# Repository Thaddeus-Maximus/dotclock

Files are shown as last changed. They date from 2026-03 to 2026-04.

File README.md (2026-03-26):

# dotclock

An ESP32-based alarm clock with a dot matrix LED display, rotary encoder interface, MP3 audio playback, and a web configuration UI.

## Features

- 32x8 dot matrix display (4x FC-16 / MAX7219 modules) with custom 3x6 pixel font
- Rotary encoder for all on-device interaction (press to cycle modes, turn to adjust)
- MP3 alarm tones stored on-chip (LittleFS, ~12MB available)
- Web UI for settings, time sync, WiFi config, and file management
- 25-step brightness (8 software PWM + 16 hardware levels)
- Persistent settings via NVS

## User Interface

The encoder button cycles through modes. The knob adjusts the value for the current mode. After 15 seconds of inactivity, the display returns to time mode.

| Mode | Icon | Knob Action | Notes |
|---|---|---|---|
| Time | (none, full-width HH:MM) | Dismisses alarm if ringing | Default mode |
| Volume | Speaker icon | 0-16 | Plays alarm tone as preview while adjusting |
| Brightness | Bulb icon | 1-24 | |
| Alarm | Bell icon | Adjusts alarm time by 1min (fast: 15min) | Scroll below 00:00 for OFF; defaults to OFF |
| Set Time | Clock icon | Adjusts system clock by 1min (fast: 15min) | |

When the alarm is ringing, the display flashes inverted at ~1.4Hz. Press button or turn knob to dismiss.

## Web Interface

WiFi AP: **dotclock** / password **dotclock1** / IP **192.168.4.1**

- Sync time from phone/browser (with timezone)
- Set alarm time, enable/disable, select alarm sound
- Adjust brightness and volume
- Connect to a WiFi network (AP+STA mode, enables SNTP)
- Upload, rename, and delete MP3 files

## Audio

- MP3 files, decoded via libhelix-mp3
- 8-bit DAC output on GPIO25 through a PAM8403 class-D amplifier
- GPIO25 driven low when idle to minimize speaker static

## Project Structure

- `HEDC-F001/` — Firmware (ESP-IDF v5.3.1 project)
- `HEDC-B002/` — Hardware (board schematic, see hardware reference below)

## TODO

- [x] Read encoder (debouncing, velocity detection)
- [x] Set display (writing, brightness control)
- [x] Custom 3x6 pixel font with 8x8 mode icons
- [x] MP3 audio playback
- [x] Alarm system with looping playback
- [x] Web interface (settings, file management, time sync)
- [x] Persistent settings (NVS)
- [x] WiFi AP + STA with SNTP
- [ ] Fine-tune font glyphs
- [ ] RC filter on DAC output for cleaner audio

# HEDC-B002 Hardware Reference

## Board Overview

The HEDC-B002 is an ESP32-based controller board with USB-C programming, SPI LED output (5V level-shifted), a rotary encoder with push button, an audio amplifier, and a 32.768kHz RTC crystal. The crystal, however, doesn't work right, it seems.

## Power

| Rail | Source | Regulator |
|---|---|---|
| +5V | USB-C (J1) | Direct from VBUS |
| +3.3V | +5V rail | U4 AMS1117-3.3 (SOT-223) |

## ESP32 GPIO Map

### Used GPIOs

| GPIO | Direction | Net Label | Function | Notes |
|---|---|---|---|---|
| IO0 | - | UART_~BOOT | Boot mode select | Auto-reset circuit via Q1. Do not use at runtime. |
| IO1 | TX | UART_TXD | Serial TX to CH340C | USB serial. Directly to J3 header pin alternate. |
| IO3 | RX | UART_RXD | Serial RX from CH340C | USB serial. |
| IO14 | Input | ES1 | Rotary encoder push switch | 5.1kΩ pull-up to 3.3V. Active LOW. |
| IO17 | Output | CS | SPI chip select | 3.3V → 5V via U1 74HCT244 → J3 pin 4 (CS_5V) |
| IO18 | Output | CLK | SPI clock | 3.3V → 5V via U1 74HCT244 → J3 pin 5 (CLK_5V) |
| IO23 | Output | DIN | SPI data out | 3.3V → 5V via U1 74HCT244 → J3 pin 3 (DIN_5V) |
| IO25 | Output | INL | Audio output to amplifier | AC-coupled into PAM8403 left channel input |
| IO26 | Input | EA1 | Rotary encoder channel A | 5.1kΩ pull-up to 3.3V |
| IO27 | Input | EB1 | Rotary encoder channel B | 5.1kΩ pull-up to 3.3V |
| IO32 | - | CRYSTAL_1 | 32.768kHz crystal (XIN) | Y1 CM315D32768DZFT, 22pF load caps (C7, C8) |
| IO33 | - | CRYSTAL_2 | 32.768kHz crystal (XOUT) | Y1 CM315D32768DZFT, 22pF load caps (C7, C8) |
| EN | - | UART_EN | Chip enable | Auto-reset circuit via Q1 + RC timing cap |

### Unused GPIOs

| GPIO | Pin # | Notes |
|---|---|---|
| IO2 | 24 | Explicitly no-connect on schematic |
| IO4 | 26 | Available |
| IO5 | 29 | Available (outputs PWM at boot) |
| IO12 | 14 | Available (boot fail if pulled high) |
| IO13 | 16 | Available |
| IO15 | 23 | Available (outputs PWM at boot) |
| IO16 | 27 | Available |
| IO19 | 31 | Available |
| IO21 | 33 | Available |
| IO22 | 36 | Available |
| IO34 | 6 | Available (input only, no pull-up/down) |
| IO35 | 7 | Available (input only, no pull-up/down) |
| SENSOR_VP (IO36) | 4 | Available (input only) |
| SENSOR_VN (IO39) | 5 | Available (input only) |

## Components

### U3 — CH340C (USB-to-Serial)

SOIC-16 USB-UART bridge. Internal oscillator (no external crystal). Connected to USB-C connector J1.

| CH340C Pin | Net | Connects To |
|---|-----|---|
| TXD | UART_TXD | ESP32 IO1 (RXD0) |
| RXD | UART_RXD | ESP32 IO3 (TXD0) |
| ~DTR | DTR | Q1 auto-reset circuit |
| ~RTS | RTS | Q1 auto-reset circuit |
| UD+/UD- | USB D+/D- | J1 USB-C connector |
| V3 | - | 100nF decoupling cap (C6) to GND |

### Q1 — MMDT3904-7-F (Auto-Reset)

Dual NPN transistor (SOT-363) implementing the standard ESP32 auto-programming circuit. Cross-coupled: RTS drives IO0 (BOOT), DTR drives EN, so a DTR/RTS sequence enters the bootloader automatically.

### U1 — 74HCT244 (Level Shifter)

TSSOP-20 octal buffer. Powered from +5V. Converts 3.3V ESP32 SPI signals to 5V for J3 output. Bank 1 active (OE tied to GND), bank 2 active but unused.

| Input (3.3V) | Output (5V) | Signal |
|---|---|---|
| 1A0 ← CS (IO17) | 1Y0 → CS_5V | Chip select |
| 1A1 ← CLK (IO18) | 1Y1 → CLK_5V | Clock |
| 1A2 ← DIN (IO23) | 1Y2 → DIN_5V | Data |

### J3 — 5-Pin LED Output Connector (FC-16 footprint)

| Pin | Signal |
|-----|---|
| 1 | +5V |
| 2 | GND |
| 3 | DIN_5V |
| 4 | CS_5V |
| 5 | CLK_5V |

This is the SPI output for driving an LED matrix or display panel.

### SW1 — PEC09-2320F-S0015 (Rotary Encoder)

Bourns horizontal-mount rotary encoder with push button. All signals pulled up to 3.3V with 5.1kΩ resistors.

| Function | Net | GPIO | Active State |
|---|-----|---|---|
| Encoder A | EA1 | IO26 | LOW pulses |
| Encoder B | EB1 | IO27 | LOW pulses |
| Push switch | ES1 | IO14 | LOW when pressed |

### U2 — PAM8403DR (Audio Amplifier)

SOP-16 class-D stereo amplifier, powered from +5V. Left channel input (INL) driven from ESP32 IO25 through a coupling capacitor. Speaker output on SPK1 header (marked DNP — do not populate).

| Connection | Detail |
|---|---|
| Input | IO25 → coupling cap → INL (pin 7) |
| Output | LOUT+/LOUT- → SPK1 (2-pin header) |
| Power | +5V / GND |

### Y1 — CM315D32768DZFT (RTC Crystal)

32.768kHz crystal connected to IO32/IO33 with 22pF load capacitors (C7, C8). Provides a precise timebase for RTC functionality.

### J1 — USB-C Connector (UJ20-C-V-C-1-SMT-TR)

USB 2.0 Type-C receptacle (14-pin). CC1/CC2 have 5.1kΩ pull-downs (R6, R7) for device identification.

## Code Quick-Reference

```cpp
// --- Pin Definitions ---

// SPI LED output (directly usable with hardware SPI: VSPI)
#define PIN_LED_CS    17  // SPI chip select
#define PIN_LED_CLK   18  // SPI clock (VSPI CLK)
#define PIN_LED_DIN   23  // SPI MOSI (VSPI MOSI)

// Rotary encoder (active LOW, external 5.1k pull-ups)
#define PIN_ENC_A     26  // Encoder channel A
#define PIN_ENC_B     27  // Encoder channel B
#define PIN_ENC_SW    14  // Encoder push switch

// Audio output (PWM/DAC → PAM8403 amplifier)
#define PIN_AUDIO     25  // DAC1 output (IO25 is DAC channel 1)

// UART (directly to CH340C — used by USB serial, avoid reassigning)
// #define PIN_TXD0    1
// #define PIN_RXD0    3

// RTC crystal (do not use as GPIO)
// IO32 — XTAL 32.768kHz XIN
// IO33 — XTAL 32.768kHz XOUT
```

### Notes for Firmware

- **SPI**: IO17/IO18/IO23 map to the default VSPI bus (CLK=18, MOSI=23). IO17 is used as CS but is not the default VSPI CS0 (IO5), so configure it manually.
- **Audio**: IO25 is one of the ESP32's two DAC outputs (DAC1). You can use `dacWrite(25, value)` for simple waveforms, or configure I2S for higher quality audio output to the PAM8403.
- **Rotary encoder**: Use interrupt-driven decoding on IO26/IO27. The push button on IO14 should be debounced in software.
- **RTC crystal**: IO32/IO33 are dedicated to the 32.768kHz crystal. Use the ESP32's internal RTC with this external crystal for accurate timekeeping. Configure via `rtc_clk_32k_enable()` or the ESP-IDF RTC API.
- **Boot strapping**: IO0 is used for boot mode (auto-reset handles this). IO2 is NC. IO12/IO15 affect boot — if using them, ensure they're not pulled to unexpected states at power-on.

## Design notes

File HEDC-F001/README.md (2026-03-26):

# HEDC-F001 Firmware

ESP-IDF v5.3.1 firmware for the dotclock alarm clock.

## Building

```
idf.py set-target esp32
idf.py build
idf.py flash monitor
```

Flash size must be set to **16MB** in menuconfig (`Serial flasher config > Flash size`).

## Partition Layout

Defined in `partitions.csv`:

| Partition | Type | Size | Purpose |
|---|---|---|---|
| nvs | data | 24KB | Settings (brightness, volume, alarm, WiFi) |
| otadata | data | 8KB | OTA state |
| ota_0 | app | 2MB | Application slot 0 |
| ota_1 | app | 2MB | Application slot 1 |
| storage | data | ~12MB | LittleFS filesystem for MP3 files |

## Source Files

| File | Description |
|---|---|
| `main.c` | App entry point, encoder UI state machine (5 modes), idle timeout |
| `display.c` | MAX7219 driver, framebuffer, 3x6 font, 8x8 mode icons, software PWM brightness |
| `display.h` | Display API, pin definitions, brightness constants, icon enum |
| `encoder.c` | Quadrature decoder via GPIO ISR, velocity detection, button debounce |
| `encoder.h` | Encoder pin definitions, state struct |
| `audio.c` | MP3 decode (libhelix-mp3) to 8-bit DAC via `dac_continuous` driver |
| `audio.h` | Audio API, volume constants |
| `settings.c` | NVS-backed persistent settings (load/save/getters/setters) |
| `settings.h` | Settings API |
| `alarm.c` | Alarm check timer (1s), looping playback, time management (epoch, timezone) |
| `alarm.h` | Alarm API, time helpers (`time_is_set`, `time_set_epoch`, `time_set_tz`) |
| `webserver.c` | HTTP server, 11 URI handlers, WiFi AP+STA, SNTP |
| `webserver.h` | Webserver API |
| `webpage.html` | Web UI source (compiled to `webpage.h` by `webpage_compile.py`) |
| `simple_dns_server.c` | Captive portal DNS responder |

## Dependencies

Defined in `idf_component.yml`:

- `chmorgan/esp-libhelix-mp3` ^1.0.3 -- MP3 decoding
- `joltwallet/littlefs` ^1.20.3 -- LittleFS filesystem

## Display

### Hardware

4x FC-16 modules (MAX7219), daisy-chained via SPI3 at 1MHz.

| Signal | GPIO |
|---|---|
| CS | 17 |
| CLK | 18 |
| DIN | 23 |

### Fonts

Two fonts are defined (3x5 is commented out, 3x6 is active):

**3x6 font** (`font_3x6`): 3 columns, 6 rows per glyph, LSB = top row. Indices:
- 0-9: digits (user-customized shapes)
- 10: minus/dash
- 11: space
- 12-37: A-Z

### Rendering Functions

| Function | Description |
|---|---|
| `display_time(h, m, colon)` | Full-width HH:MM with double-thick colon, y-offset 1 |
| `display_dashes()` | Full-width --:-- (same layout as time, for "not set" state) |
| `display_text(str)` | Left-aligned text |
| `display_number(num)` | Right-aligned number |
| `display_icon_time(icon, h, m)` | 8x8 icon on panel 0 + HHMM on panels 1-3 |
| `display_icon_number(icon, num)` | 8x8 icon on panel 0 + number centered on panels 1-3 |
| `display_icon_text(icon, str)` | 8x8 icon on panel 0 + text centered on panels 1-3 |
| `display_invert()` | XOR entire framebuffer (used for alarm flash) |

### Brightness

25 levels (0-24). `DISPLAY_BRIGHTNESS_MAX` = 24.

- Level 0: display off
- Levels 1-8: software PWM at hardware intensity 0 (~500Hz, 8 duty phases)
- Levels 9-24: hardware intensity registers 0-15

PWM race condition is handled by setting `pwm_duty = 0` before `esp_timer_stop()`.

### Mode Icons

8x8 pixel icons stored as column bytes (MSB = top), one per UI mode:

| Icon | Enum | Usage |
|---|---|---|
| Bell | `DISPLAY_ICON_ALARM` | Alarm time setting |
| Clock | `DISPLAY_ICON_SET_TIME` | System time setting |
| Speaker | `DISPLAY_ICON_VOLUME` | Volume adjustment |
| Bulb | `DISPLAY_ICON_BRIGHTNESS` | Brightness adjustment |

## Encoder

PEC09 rotary encoder with quadrature decoding in ISR. `DRAM_ATTR` is required on the lookup table (ISR runs with flash cache disabled during NVS/LittleFS writes).

- 2 raw edges per detent, divided by 2 in `encoder_read()`
- Velocity detection via ring buffer of edge timestamps
- Fast threshold: 100 detents/sec
- Button debounce: 20ms in ISR

## Audio

- MP3 decode via libhelix-mp3 in a dedicated FreeRTOS task (priority 10)
- Output: `dac_continuous` driver on GPIO25 (DAC1), 8-bit mono
- DMA: 8 descriptors x 2048 bytes, input buffer 4096 bytes
- GPIO25 driven low when not playing to reduce idle speaker static
- Volume: 16 levels, applied as bit-shift attenuation on PCM samples

## Alarm

- 1-second `esp_timer` callback checks if current time matches alarm time
- When triggered, plays the selected MP3 file in a loop (re-triggers on playback end)
- Dismissed by encoder button press or knob turn
- Display flashes inverted at ~1.4Hz (350ms per phase) while ringing
- Alarm defaults to OFF; enabled by scrolling up from OFF in the alarm menu
- Scrolling below 00:00 sets alarm to OFF; scrolling above 23:59 wraps to 00:00

## Settings (NVS)

NVS namespace: `dotclock`

| Key | Type | Default | Description |
|-----|---|---|---|
| brightness | u8 | 1 | Display brightness (1-24) |
| volume | u8 | 8 | Audio volume (0-16) |
| alm_hour | u8 | 0 | Alarm hour |
| alm_min | u8 | 0 | Alarm minute |
| alm_en | u8 | 0 | Alarm enabled |
| alm_file | string | "" | Alarm sound filename |
| wifi_ssid | string | "" | STA WiFi SSID |
| wifi_pass | string | "" | STA WiFi password |

## Web Server

WiFi SoftAP is always active: SSID `dotclock`, password `dotclock1`, IP `192.168.4.1`. Optional STA mode connects to a saved WiFi network (AP+STA concurrent).

### Endpoints

| Method | Path | Description |
|---|---|---|
| GET | `/` | Serve web UI (compiled from `webpage.html`) |
| GET | `/settings` | JSON: all settings + current time + WiFi status |
| POST | `/settings` | Update settings (form-encoded) |
| POST | `/time` | Set epoch + timezone offset (from browser) |
| POST | `/wifi` | Save WiFi credentials and connect |
| GET | `/files` | JSON array of files on storage |
| POST | `/upload` | Upload file (multipart/form-data) |
| POST | `/delete` | Delete file (`?file=name`) |
| POST | `/rename` | Rename file (`?from=old&to=new`) |
| POST | `/alarm/test` | Play alarm sound immediately |
| POST | `/alarm/stop` | Stop alarm playback |

### Time Sync

The browser sends `Math.floor(Date.now()/1000)` as epoch and `new Date().getTimezoneOffset()` as tz offset. The ESP32 sets the system clock and configures a POSIX TZ environment variable. When STA WiFi is connected, SNTP is also enabled.

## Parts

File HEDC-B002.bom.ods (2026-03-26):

Reference | Value | Datasheet | Footprint | Qty | DNP | DIGIKEY PN
C1,C2,C5 | 100nF | ~ | Capacitor_SMD:C_0603_1608Metric | 3 |  | 1276-1012-1-ND
C3,C4,C6 | 1uF | ~ | Capacitor_SMD:C_0603_1608Metric | 3 |  | 1276-1946-1-ND
C7,C11 | 470nF | ~ | Capacitor_SMD:C_0603_1608Metric | 2 |  | 1276-1062-1-ND
C8,C9 | 22pF | ~ | Capacitor_SMD:C_0603_1608Metric | 2 |  | 1276-1023-1-ND
J2 | Conn_01x02 | ~ | Connector_PinHeader_2.54mm:PinHeader_1x02_P2.54mm_Vertical | 1
J4 | Conn_01x05 | ~ | footprints:FC-16 | 1
J5 | USB_C_Receptacle_USB2.0_14P | https://www.usb.org/sites/default/files/documents/usb_type-c.zip | Connector_USB:USB_C_Receptacle_GCT_USB4115-03-C | 1 |  | 2223-UJ20-C-V-C-1-SMT-TRCT-ND
Q3 | MMDT3904 | http://www.diodes.com/_files/datasheets/ds30088.pdf | Package_TO_SOT_SMD:SOT-363_SC-70-6 | 1 |  | MMDT3904-FDICT-ND
R1,R2,R3,R4,R5,R6,R7,R8,R9 | 5.1k | ~ | Resistor_SMD:R_0805_2012Metric | 9 |  | CR0805-FX-5101ELFCT-ND
SW1 | PEC11H-4120F-S0020 | PEC11H-4120F-S0020 | Rotary_Encoder:RotaryEncoder_Bourns_Horizontal_PEC09-2xxxF-Sxxxx | 1 |  | PEC09-2320F-S0015-ND
U1 | CH340C | https://datasheet.lcsc.com/szlcsc/Jiangsu-Qin-Heng-CH340C_C84681.pdf | Package_SO:SOIC-16_3.9x9.9mm_P1.27mm | 1
U2 | 74HCT04 | https://assets.nexperia.com/documents/data-sheet/74HC_HCT04.pdf | Package_SO:TSSOP-14_4.4x5mm_P0.65mm | 1 |  | 31-74HCT04T14-13CT-ND
U3 | PAM8403D | https://www.diodes.com/assets/Datasheets/products_inactive_data/PAM8403.pdf | Package_SO:SOP-16_3.9x9.9mm_P1.27mm | 1 |  | PAM8403DRDICT-ND
U5 | ESP32-WROOM-32 | https://www.espressif.com/sites/default/files/documentation/esp32-wroom-32_datasheet_en.pdf | RF_Module:ESP32-WROOM-32 | 1
U8 | AMS1117-3.3 | http://www.advanced-monolithic.com/pdf/ds1117.pdf | Package_TO_SOT_SMD:SOT-223-3_TabPin2 | 1 |  | 4518-AMS1117-3.3CT-ND
Y1 | CM315D32768DZFT |  | footprints:XTAL_CM315D32768DZFT | 1 |  | 300-8814-1-ND

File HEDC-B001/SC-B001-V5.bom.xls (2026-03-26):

Id | Designator | Footprint | Quantity | Designation | PN | Supplier | DigiKey PN
14 | C1 | CP_Elec_10x12.5 | 1 | 680uF | A783MW687M1VLAS011 | DigiKey | 399-A783MW687M1VLAS011CT-ND
33 | C11,C10 | C_0603_1608Metric | 2 | 22pF | CL10C220JB8NNNC | DigiKey | 1276-1023-1-ND
15 | C2,C12,C3 | C_0805_2012Metric | 3 | 4.7uF | CL21A475KLCLQNC | DigiKey | 1276-6722-1-ND
10 | C4 | C_0603_1608Metric | 1 | 1nF | CL10B102KB8NNNC | DigiKey | 1276-1018-1-ND
19 | C5 | CP_Elec_8x10 | 1 | 220uF | A787KN227M1VLAS027 | DigiKey | 399-A787KN227M1VLAS027CT-ND
7 | C6,C14,C9 | C_0603_1608Metric | 3 | 100nF | CL10F104ZB8NNNC | DigiKey | 1276-1012-2-ND
5 | D3,D4,D5,D1,D2 | D_SMA | 5 | B340A-13-F | B340A-13-F | DigiKey | B340A-FDICT-ND
22 | J_RF1 | RX470C-V01 | 1 | RX470-4 | RX470C-V01 | QiaChip
2 | J1,J2,J3,J4 | JST_EH_B3B-EH-A_1x03_P2.50mm_Vertical | 4 | B3B-EH-A | B3B-EH-A | DigiKey | 455-B3B-EH-A-ND
23 | J7 | PinHeader_1x07_P2.54mm_Vertical | 1 | Conn_01x07 | PH1-07-UA | DigiKey | 2057-PH1-07-UA-ND
 | J8 | MSD-1-A | 1 | MSA-1-A | MSA-1-A | DigiKey | 2223-MSD-1-ATR-ND
3 | JA3,JA1,JB2,J_PV-1,J_BAT+1,J_BAT-1,JB1,JA2,J_PV+1,J_GND1,J_BAT+2 | TE_1217861-1 | 11 | Conn_01x01_Pin | 1217861-1 | DigiKey | A100452TR-ND
16 | KA3,KA2,KB2 | RELAY_A161CS12VDC.64 | 3 | A161CS12VDC.64 | A161CS12VDC.64 | DigiKey | 2449-A161CS12VDC.64-ND
4 | KB1,KA1 | A31CSP12VDC2 | 2 | A31CSP12VDC2 | A31CSP12VDC2 | DigiKey | 2449-A31CSP12VDC2-ND
28 | L1 | IND_IFDC5050HZER_VIS | 1 | IFDC5050HZER330M | IFDC5050HZER330M | DigiKey | 541-IFDC5050HZER330MCT-ND
36 | L2 | RES_CIGT201610_SAM | 1 | CIGT201610LH2R2MNE | CIGT201610LH2R2MNE | DigiKey | 1276-6911-1-ND
29 | LED1 | WP934SA&slash_3GD_KNB | 1 | WP934SA/3GD | WP934SA/3GD | DigiKey | 754-1289-ND
12 | Q1,Q2 | SOT-23 | 2 | 2N7002 | 2N7002 | DigiKey | 2N7002NCT-ND
21 | R1 | R_0805_2012Metric | 1 | 22k | CRCW080522K0FKEAC | DigiKey | 541-4150-1-ND
27 | R11,R12,R13,R14 | R_0805_2012Metric | 4 | 1k | CRCW08051K00FKEAC | DigiKey | 541-3977-1-ND
6 | R17,R16,R15 | R_0805_2012Metric | 3 | 100 | CRCW0805100RFKEAC | DigiKey | 541-3979-1-ND
9 | R19,R9,R8,R18,R7,R20,R23 | R_0805_2012Metric | 7 | 4.7k | CRCW08054K70FKEAC | DigiKey | 541-4131-1-ND
30 | R2 | R_0805_2012Metric | 1 | 2.2k | CRCW08052K20FKEA | DigiKey | 541-2.20KCCT-ND
24 | R3 | R_0805_2012Metric | 1 | 33k | CRCW080533K0FKEA | DigiKey | 541-33.0KCCT-ND
26 | R4 | R_0805_2012Metric | 1 | 1M | CRCW08051M00FKEAC | DigiKey | 541-4135-1-ND
20 | R5 | R_0805_2012Metric | 1 | 150k | CRCW0805150KFKEAC | DigiKey | 541-CRCW0805150KFKEACCT-ND
31 | R6 | R_0805_2012Metric | 1 | 42.2k | CRCW080542K2FKEA | DigiKey | 541-42.2KCCT-ND
8 | SW1 | SW_Tactile_SPST_Angled_PTS645Vx31-2LFS | 1 | TS11-674-80-BK-260-RA-D | TS11-674-80-BK-260-RA-D | DigiKey | 2223-TS11-674-80-BK-260-RA-D-ND
13 | U1 | VREG_LM2596S-ADJ | 1 | LM2596S-ADJ | LM2596S-ADJ | DigiKey | LM2596DSADJGOS-ND
1 | U11 | TSSOP-24_4.4x7.8mm_P0.65mm | 1 | TCA9535PWR | NCA9535PWJ | DigiKey | 1727-NCA9535PWJTR-ND
17 | U2 | SOTFL50P160X60-8N | 1 | TPS629210DRLR | TPS629210DRLR | DigiKey | 296-TPS629210DRLRCT-ND
34 | U3 | ESP32-WROOM-32 | 1 | ESP32-WROOM-32 | ESP32-WROOM-32E-N8 | DigiKey | 5407-ESP32-WROOM-32E-N8TR-ND
35 | U4 | SOIC127P600X175-16N | 1 | ULN2003ADR | ULN2003ADR | DigiKey | 296-1368-1-ND
25 | U5,U6 | SMDIP-8_W9.53mm | 2 | LTV-827S | LTV-827S | DigiKey | 160-1369-5-ND
11 | U9 | ACS37220LEZATR200B5 | 1 | ACS37220LEZATR-100B3 | ACS37220LEZATR-100B3 | DigiKey | 620-ACS37220LEZATR-100B3CT-ND
32 | Y1 | XTAL_CM315D32768DZFT | 1 | CM315D32768DZFT | CM315D32768DZFT | DigiKey | 300-8814-1-ND

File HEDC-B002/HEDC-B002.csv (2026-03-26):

Id | Designator | Footprint | Quantity | Designation | Supplier and ref
1 | R2,R11,R8,R4,R6,R1,R3,R9,R7,R10 | R_0805_2012Metric | 10 | 5.1k | CR0805-FX-5101ELFCT-ND
2 | SW1 | RotaryEncoder_Bourns_Horizontal_PEC09-2xxxF-Sxxxx | 1 | PEC09-2320F-S0015 | PEC09-2320F-S0015-ND
3 | C4,C5,C10 | C_0603_1608Metric | 3 | 1uF | 1276-1946-1-ND
4 | C9,C1,C6 | C_0603_1608Metric | 3 | 100nF | 1276-1012-1-ND
5 | C2,C3 | C_0603_1608Metric | 2 | 470nF | 1276-1062-1-ND
6 | J1 | USB_C_Receptacle_GCT_USB4115-03-C | 1 | UJ20-C-V-C-1-SMT-TR | 2223-UJ20-C-V-C-1-SMT-TRCT-ND
7 | C7,C8 | C_0603_1608Metric | 2 | 22pF | 1276-1023-1-ND
8 | U1 | TSSOP-20_4.4x6.5mm_P0.65mm | 1 | 74HCT244 | MC74HCT244ADTGOSCT-ND
9 | SPK1 | PinHeader_1x02_P2.54mm_Vertical | 1 | Conn_01x02
10 | Q1 | SOT-363_SC-70-6 | 1 | MMDT3904-7-F | MMDT3904-FDICT-ND
11 | U2 | SOP-16_3.9x9.9mm_P1.27mm | 1 | PAM8403DR | PAM8403DRDICT-ND
12 | U3 | SOIC-16_3.9x9.9mm_P1.27mm | 1 | CH340C
13 | U4 | SOT-223-3_TabPin2 | 1 | AMS1117-3.3 | 4518-AMS1117-3.3CT-ND
14 | R5 | R_0805_2012Metric | 1 | 2.7k | CR0805-FX-2701ELFCT-ND
15 | U5 | ESP32-WROOM-32 | 1 | ESP32-WROOM-32
16 | Y1 | XTAL_CM315D32768DZFT | 1 | CM315D32768DZFT | 300-8814-1-ND
17 | J3 | FC-16 | 1 | Conn_01x05
Id | Designator | Footprint | Quantity | Designation | Supplier and ref
1 | TH3,TH1,TH2 | R_0805_2012Metric | 3 | SMD0805B100TFT | SMD0805B050TF
2 | U11,U12 | SOIC127P600X175-16N | 2 | ULN2003ADR | 296-1368-1-ND
3 | D1 | D_SMA | 1 | B340A-13-F | B340A-FDICT-ND
4 | C2,C17,C11,C1,C9,C15,C12,C10,C16,C14 | C_0603_1608Metric | 10 | 100nF | 1276-1012-1-ND
5 | C4,C7,C13,C6,C8 | C_0805_2012Metric | 5 | 4.7uF
6 | K7,K11,K5,K1,K3,K2,K4,K8,K6,K12,K9,K10 | RELAY_A161CS12VDC.64 | 12 | A161CS12VDC.64 | 2449-A161CS12VDC.64-ND
7 | U9 | TSSOP-20_4.4x6.5mm_P0.65mm | 1 | 74HCT244 | MC74HCT244ADTGOSCT-ND
8 | U6,U8,U7 | TSSOP-14_4.4x5mm_P0.65mm | 3 | MCP3204 | MCP3204T-CI/STCT-ND
9 | ,,,, |  | 5
10 | D2,D3,D4 | LED_D5.0mm | 3 | LED | 2007-BL-BBX1V4V-2-B02-ND
11 | R17,R14,R18 | R_0805_2012Metric | 3 | 100 | CR0805-FX-1000ELFCT-ND
12 | J1,J2 | AT04-4P-BMxx | 2 | Conn_01x04 | 889-1893-ND
13 | J_BAT-1,J_BAT+1 | S93520 | 2 | S93520 | 2101-S93520-ND
14 | R11 | R_0805_2012Metric | 1 | 80.6k | CR0805-FX-8062ELFCT-ND
15 | R6,R3,R13,R5,R4,R1,R2 | R_0805_2012Metric | 7 | 10k | CR0805-FX-1002ELFCT-ND
16 | U5,U3 | SOTFL50P160X60-8N | 2 | TPS629210DRLR
17 | R15,R12,R16 | R_0805_2012Metric | 3 | 5.1k | CR0805-FX-5101ELFCT-ND
18 | C5 | CP_Elec_10x12.5 | 1 | 680uF
19 | J3 | AT04-6P-BMXX | 1 | Conn_01x06
20 | U14,U15,U13 | XDCR_ACS71240KEXBLT-050U5 | 3 | ACS71240KEXBLT-050U5 | 620-2050-1-ND
21 | L1,L2 | RES_CIGT201610_SAM | 2 | CIGT201610LH2R2MNE | 1276-6911-1-ND
22 | U4 | ESP32-WROOM-32 | 1 | ESP32-WROOM-32
23 | J6,J4,J5 | AT04-12PX-BMXX | 3 | Conn_01x12 | 889-1923-ND
24 | R8 | R_0805_2012Metric | 1 | 150k | CR0805-FX-1503ELFCT-ND
25 | R7 | R_0805_2012Metric | 1 | 1M | CR0805-FX-1004ELFCT-ND
26 | U1 | DBZ0003A-MFG | 1 | DRV5033AJQDBZR | 296-38454-1-ND
27 | U10 | TSSOP-24_4.4x7.8mm_P0.65mm | 1 | TCA9535PWR | 296-25129-1-ND
28 | R9,R10 | R_0805_2012Metric | 2 | 42.2k | CR0805-FX-4222ELFCT-ND
Id | Designator | Footprint | Quantity | Designation | Supplier and ref
1 | TH2,TH1 | R_0805_2012Metric | 2 | SMD0805B100TFT
2 | R6,R2,R4,R3,R13,R7,R5,R1,R8 | R_0805_2012Metric | 9 | 4.7k
3 | C5,C7 | C_0603_1608Metric | 2 | 100nF
4 | R9 | R_0805_2012Metric | 1 | 120
5 | C3,C4,C2 | C_0805_2012Metric | 3 | 4.7uF
6 | R10 | R_0805_2012Metric | 1 | 1M
7 | J4,J5,J6 | PhoenixContact_SPT_1.5_2-H-3.5_1x02_P3.5mm_Horizontal | 3 | Conn_01x02
8 | Q1 | SOT-23 | 1 | 2N7002 | 4878-2N7002CT-ND
9 | U2 | SOTFL50P160X60-8N | 1 | TPS629210DRLR
10 | J1 | PinSocket_1x07_P2.54mm_Vertical | 1 | Conn_01x07
11 | U1 | ESP32-WROOM-32 | 1 | ESP32-WROOM-32
12 | J2 | TE_2-1734839-5_1x25-1MP_P0.5mm_Horizontal | 1 | Conn_01x25
13 | D4 | D_SMA | 1 | B340A-13-F
14 | L2 | RES_CIGT201610_SAM | 1 | CIGT201610LH2R2MNE
15 | R12 | R_0805_2012Metric | 1 | 42.2k | CR0805-FX-4222ELFCT-ND
16 | R11 | R_0805_2012Metric | 1 | 150k | CR0805-FX-1503ELFCT-ND
17 | C1 | CP_Elec_10x12.5 | 1 | 680uF
18 | SW8,SW6,SW5,SW4,SW7,SW3 | SW_PUSH_6mm_H9.5mm | 6 | SW_Push | 2223-TS02-66-100-BK-260-SCR-D-ND
19 | SW2,SW1 | PEC11H-4x20F-Sxxxx_BRN | 2 | PEC11H-4120F-S0020 | 118-PEC11H-4120F-S0020-ND
20 | J3 | G240160A-FTW-DW63 | 1 | Conn_01x02 | 2632-G240160A-FTW-DW63-ND

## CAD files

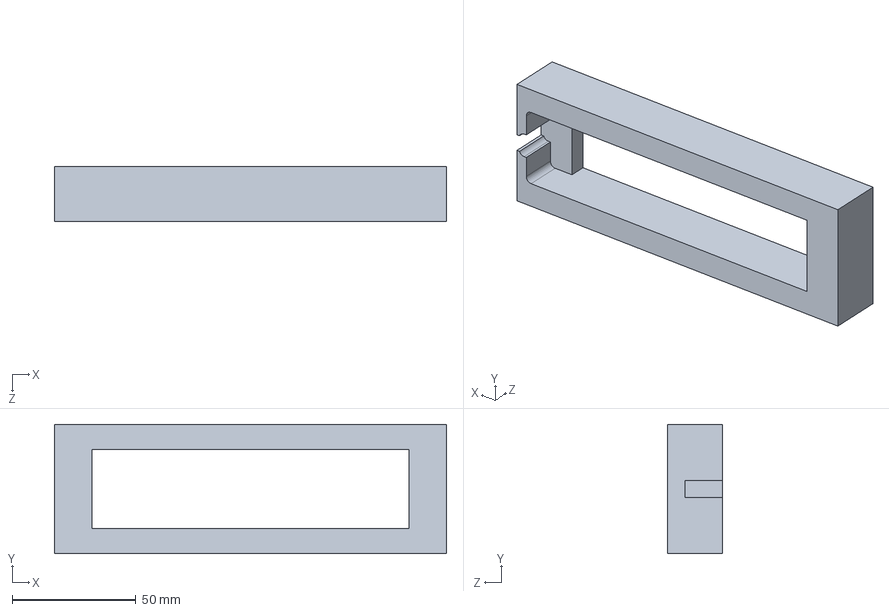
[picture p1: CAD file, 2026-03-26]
HEDC-0001.SLDPRT
158.5 x 52.3 x 22.2 mm

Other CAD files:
HEDC-0001.SLDDRW

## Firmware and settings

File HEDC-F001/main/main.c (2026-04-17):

#include <stdio.h>
#include <time.h>
#include <sys/time.h>
#include "freertos/FreeRTOS.h"
#include "freertos/task.h"
#include "esp_littlefs.h"
#include "esp_log.h"
#include "encoder.h"
#include "display.h"
#include "audio.h"
#include "settings.h"
#include "alarm.h"
#include "webserver.h"

static const char *TAG = "main";

extern bool time_is_set(void);
extern void time_set_epoch(int64_t epoch);

typedef enum {
	MODE_TIME,
	MODE_ALARM,
	MODE_VOLUME,
	MODE_BRIGHTNESS,
	MODE_SET_TIME,
	MODE_NETWORK,
	MODE_COUNT
} ui_mode_t;

#define IDLE_TIMEOUT  1500  // 15 seconds at 10ms ticks

// Default epoch for initial time set (2025-01-01 12:00:00 UTC)
#define DEFAULT_EPOCH 1735732800LL

static void init_storage(void)
{
	esp_vfs_littlefs_conf_t cfg = {
		.base_path = "/storage",
		.partition_label = "storage",
		.format_if_mount_failed = true,
		.dont_mount = false,
	};
	esp_err_t ret = esp_vfs_littlefs_register(&cfg);
	if (ret != ESP_OK) {
		ESP_LOGE(TAG, "LittleFS mount failed: %s", esp_err_to_name(ret));
		return;
	}

	size_t total = 0, used = 0;
	esp_littlefs_info("storage", &total, &used);
	ESP_LOGI(TAG, "Storage: %d KB total, %d KB used", total / 1024, used / 1024);
}

// Adjust alarm time by delta minutes
// Below 00:00 → OFF; above 23:59 → wraps to 00:00
// From OFF, scrolling up → 00:00 (enabled)
static void adjust_alarm_time(int delta)
{
	if (!settings_get_alarm_enabled()) {
		if (delta > 0) {
			settings_set_alarm_enabled(true);
			settings_set_alarm_time(0, 0);
			alarm_reschedule();
		}
		return;
	}

	int total = settings_get_alarm_hour() * 60 + settings_get_alarm_minute() + delta;

	if (total < 0) {
		// Scrolled below 00:00 → OFF
		settings_set_alarm_enabled(false);
		alarm_reschedule();
		return;
	}

	// Wrap at top (23:59 + 1 → 00:00, stays enabled)
	total = total % (24 * 60);

	settings_set_alarm_time(total / 60, total % 60);
	alarm_reschedule();
}

// Adjust the system clock by delta minutes
static void adjust_system_time(int delta)
{
	// Seed with a reasonable epoch if time was never set
	if (!time_is_set()) {
		time_set_epoch(DEFAULT_EPOCH);
	}

	struct timeval tv;
	gettimeofday(&tv, NULL);
	tv.tv_sec += delta * 60;
	if (tv.tv_sec < 0) tv.tv_sec = 0;
	settimeofday(&tv, NULL);
}

// Start/stop volume preview tone on mode transitions
static void on_mode_change(ui_mode_t prev, ui_mode_t next)
{
	if (next == MODE_VOLUME && prev != MODE_VOLUME) {
		// Entering volume mode: play alarm tone for preview
		char path[64];
		snprintf(path, sizeof(path), "/storage/%s", settings_get_alarm_file());
		audio_play(path);
	} else if (prev == MODE_VOLUME && next != MODE_VOLUME) {
		// Leaving volume mode: stop preview
		audio_stop();
	}

	if (next == MODE_NETWORK && prev != MODE_NETWORK) {
		webserver_set_ap_enabled(true);
	} else if (prev == MODE_NETWORK && next != MODE_NETWORK) {
		webserver_set_ap_enabled(false);
	}
}

// Network mode scroll state
static int net_scroll_offset = 0;
static int net_scroll_timer = 0;
#define NET_SCROLL_RATE  6   // pixels per tick (60ms per pixel at 10ms loop)
#define NET_SCROLL_PAUSE 40  // ticks to pause at start/end (400ms)

// Show the current value for the active mode
static void show_mode_value(ui_mode_t mode)
{
	switch (mode) {
	case MODE_TIME:
		if (time_is_set()) {
			time_t now;
			time(&now);
			struct tm tm;
			localtime_r(&now, &tm);
			display_time(tm.tm_hour, tm.tm_min, true);
		} else {
			display_dashes();
		}
		break;
	case MODE_VOLUME:
		display_icon_number(DISPLAY_ICON_VOLUME, settings_get_volume());
		break;
	case MODE_BRIGHTNESS:
		display_icon_number(DISPLAY_ICON_BRIGHTNESS, settings_get_brightness());
		break;
	case MODE_ALARM:
		if (settings_get_alarm_enabled()) {
			display_icon_time(DISPLAY_ICON_ALARM,
			                  settings_get_alarm_hour(),
			                  settings_get_alarm_minute());
		} else {
			display_icon_text(DISPLAY_ICON_ALARM, "off");
		}
		break;
	case MODE_SET_TIME: {
		time_t now;
		time(&now);
		struct tm tm;
		localtime_r(&now, &tm);
		display_icon_time(DISPLAY_ICON_SET_TIME, tm.tm_hour, tm.tm_min);
		break;
	}
	case MODE_NETWORK: {
		char info[32];
		webserver_get_sta_ip(info, sizeof(info));
		int text_w = display_text_width(info);
		if (text_w <= DISPLAY_WIDTH) {
			display_text(info);
			net_scroll_offset = 0;
			net_scroll_timer = 0;
		} else {
			int max_scroll = text_w - DISPLAY_WIDTH;
			net_scroll_timer++;
			if (net_scroll_timer >= NET_SCROLL_RATE) {
				net_scroll_timer = 0;
				net_scroll_offset++;
			}
			// Total cycle: pause + scroll + pause + reset
			int total = NET_SCROLL_PAUSE + max_scroll + NET_SCROLL_PAUSE;
			int phase = net_scroll_offset % total;
			int offset;
			if (phase < NET_SCROLL_PAUSE)
				offset = 0;
			else if (phase < NET_SCROLL_PAUSE + max_scroll)
				offset = phase - NET_SCROLL_PAUSE;
			else
				offset = max_scroll;
			display_text_scroll(info, offset);
		}
		break;
	}
	default:
		break;
	}
}

void app_main(void)
{
	encoder_init();
	display_init();
	init_storage();
	audio_init();
	webserver_init();
	settings_init();
	alarm_init();
	webserver_try_sta_connect();

	display_text("ready");
	display_update();
	ESP_LOGI(TAG, "WiFi AP: dotclock / dotclock1");

	ui_mode_t mode = MODE_TIME;
	int32_t prev_pos = 0;
	int idle_count = 0;
	int flash_count = 0;
	bool flash_inverted = false;

	while (1) {
		encoder_state_t enc = encoder_read();
		int32_t delta = enc.position - prev_pos;
		prev_pos = enc.position;

		// --- Button press: dismiss alarm or cycle mode ---
		if (enc.button_changed && enc.button) {
			if (alarm_is_ringing()) {
				alarm_dismiss();
				ui_mode_t prev = mode;
				mode = MODE_TIME;
				on_mode_change(prev, mode);
				idle_count = 0;
			} else {
				ui_mode_t prev = mode;
				mode = (mode + 1) % MODE_COUNT;
				on_mode_change(prev, mode);
				idle_count = 0;
				if (mode == MODE_NETWORK) {
					net_scroll_offset = 0;
					net_scroll_timer = 0;
				}
			}
			show_mode_value(mode);
		}

		// --- Knob turn: action depends on mode ---
		if (delta != 0) {
			idle_count = 0;

			switch (mode) {
			case MODE_TIME:
				if (alarm_is_ringing()) {
					alarm_dismiss();
				} else {
					int bri = settings_get_brightness() + delta;
					if (bri < 1) bri = 1;
					if (bri > DISPLAY_BRIGHTNESS_MAX) bri = DISPLAY_BRIGHTNESS_MAX;
					settings_set_brightness(bri);
				}
				break;

			case MODE_VOLUME: {
				int vol = settings_get_volume() + delta;
				settings_set_volume(vol);
				// Restart preview if it finished
				if (!audio_is_playing()) {
					char path[64];
					snprintf(path, sizeof(path), "/storage/%s", settings_get_alarm_file());
					audio_play(path);
				}
				break;
			}

			case MODE_BRIGHTNESS: {
				int bri = settings_get_brightness() + delta;
				if (bri < 1) bri = 1;
				if (bri > DISPLAY_BRIGHTNESS_MAX) bri = DISPLAY_BRIGHTNESS_MAX;
				settings_set_brightness(bri);
				break;
			}

			case MODE_ALARM: {
				static const int step_table[] = {1, 5, 15};
				adjust_alarm_time(delta * step_table[enc.speed]);
				break;
			}

			case MODE_SET_TIME: {
				static const int step_table[] = {1, 5, 15};
				adjust_system_time(delta * step_table[enc.speed]);
				break;
			}

			default:
				break;
			}

			show_mode_value(mode);
		}

		// --- Idle timeout: return to time mode (suspended in network mode) ---
		idle_count++;
		if (mode != MODE_TIME && mode != MODE_NETWORK && idle_count > IDLE_TIMEOUT) {
			on_mode_change(mode, MODE_TIME);
			mode = MODE_TIME;
		}

		// --- Periodic display refresh (clock ticks, etc.) ---
		if (delta == 0 && !(enc.button_changed && enc.button)) {
			show_mode_value(mode);
		}

		// --- Alarm flash: invert display at ~1.4Hz (350ms per phase) ---
		if (alarm_is_ringing()) {
			flash_count++;
			if (flash_count >= 35) {  // 350ms at 10ms ticks
				flash_count = 0;
				flash_inverted = !flash_inverted;
			}
			if (flash_inverted) {
				display_invert();
			}
		} else {
			flash_count = 0;
			flash_inverted = false;
		}

		display_update();
		vTaskDelay(pdMS_TO_TICKS(10));
	}
}

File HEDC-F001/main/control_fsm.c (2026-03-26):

/*
 * control_fsm.c
 *
 *  Created on: Nov 10, 2025
 *      Author: Thad
 */

#include "control_fsm.h"
#include "esp_task_wdt.h"
#include "esp_timer.h"
#include "i2c.h"
#include "power_mgmt.h"
#include "rtc_wdt.h"
#include "driver/gpio.h"
#include "storage.h"
#include "rtc.h"
#include "sensors.h"
#include "esp_log.h"

#define TRANSITION_DELAY_US 1000000

#define CALIBRATE_JACK_MAX_TIME  3000000
#define CALIBRATE_DRIVE_MAX_TIME 6000000

#define TAG "FSM"

static QueueHandle_t fsm_cmd_queue = NULL;
	
// map from relay number to bridge
bridge_t bridge_map[] = {
	BRIDGE_AUX,
	BRIDGE_AUX,
	BRIDGE_AUX,
	BRIDGE_AUX,
	BRIDGE_JACK,
	BRIDGE_JACK,
	BRIDGE_DRIVE,
	BRIDGE_DRIVE };

bool relay_states[8] = {false};
int64_t override_times[8] = {-1};
int64_t override_cooldown[8] = {-1};
bool enabled = false;


RTC_DATA_ATTR float remaining_distance = 0.0f;
float fsm_get_remaining_distance(void)    { return remaining_distance; }
void  fsm_set_remaining_distance(float x) { remaining_distance = x;}

// Track the starting encoder count for the current move
static int32_t move_start_encoder = 0;

// Track total jack up time to use for jack down duration
static int64_t jack_up_total_time = 0;

volatile fsm_state_t current_state = STATE_IDLE;
volatile int64_t current_time = 0;
volatile bool start_running_request = false;

void setRelay(int8_t relay, bool state) {
	relay_states[relay] = state;
}

bool isRunning() {
	for (int i=0;i<8;i++) {
		if (relay_states[i]) return true;
	}
	return false;
}

void driveRelays() {
	uint8_t state = 0x00;
	//relay_states[0] = (current_time / 1000000) % 2; // for testing purposes
	
	for (uint8_t i=0; i<8; i++) {
		// if we command and efuse permits it set the relay
		if (relay_states[i] && !efuse_is_tripped(bridge_map[i])) {
			state |= 0x01<<i;
			set_autozero(bridge_map[i]);
		}
	}
	
	//ESP_LOGI(TAG, "RELAY STATE: %x", state);
	i2c_set_relays(state);
}



fsm_state_t fsm_get_state() {
	return current_state;
}

static int64_t timer_end = 0;
static int64_t timer_start = 0;
static inline void set_timer(uint64_t us) {
	timer_end = current_time + us;
	timer_start = current_time;
}
static inline bool timer_done() { return current_time >= timer_end; }

void pulseOverride(relay_t relay) {
    if (current_state == STATE_IDLE) {
        // Check if this relay is in cooldown
        if (override_cooldown[relay] > current_time) {
            // Still cooling down, ignore the command
            return;
        }
        override_times[relay] = current_time + get_param_value_t(PARAM_RF_PULSE_LENGTH).u32;
    }
}

/*void fsm_begin_auto_move() {
	if (current_state == STATE_IDLE)
		current_state = STATE_MOVE_START_DELAY;
	set_timer(TRANSITION_DELAY_US);
}*/

int64_t fsm_cal_t, fsm_cal_e;
float fsm_cal_val;
void fsm_set_cal_val(float v) {fsm_cal_val = v;}
int64_t fsm_get_cal_t(){return fsm_cal_t;}
int64_t fsm_get_cal_e(){return fsm_cal_e;}

void fsm_request(fsm_cmd_t cmd)
{
	if (fsm_cmd_queue != NULL)
	    xQueueSend(fsm_cmd_queue, &cmd, 0);  // Safe from any context
}

int8_t fsm_get_current_progress(int8_t denominator) {
	int8_t x = 0;
	switch (current_state) {
		case STATE_DRIVE:
		case STATE_JACK_UP_START:
		case STATE_JACK_UP:
		case STATE_JACK_DOWN:
		case STATE_MOVE_START_DELAY:
		case STATE_DRIVE_START_DELAY:
		case STATE_DRIVE_END_DELAY:
		case STATE_UNDO_JACK:
			if (timer_end != timer_start)
				x = (current_time-timer_start)*denominator/(timer_end-timer_start);
			break;
		case STATE_UNDO_JACK_START:
			x = 0;
			break;
		default:
			break;
	}
	if (x<0) x=0;
	if (x>denominator-1) x=denominator-1;
	return x;
}


#define JACK_TIME  get_param_value_t(PARAM_JACK_KT).f32  * get_param_value_t(PARAM_JACK_DIST ).f32
#define DRIVE_TIME get_param_value_t(PARAM_DRIVE_KT).f32 * get_param_value_t(PARAM_DRIVE_DIST).f32
#define DRIVE_DIST get_param_value_t(PARAM_DRIVE_KE).f32 * get_param_value_t(PARAM_DRIVE_DIST).f32

void control_task(void *param) {
	esp_task_wdt_add(NULL);
	
    TickType_t xLastWakeTime = xTaskGetTickCount();
    const TickType_t xFrequency = pdMS_TO_TICKS(20);
    enabled = true;
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

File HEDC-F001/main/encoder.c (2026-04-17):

#include "encoder.h"

#include "driver/gpio.h"
#include "hal/gpio_ll.h"
#include "esp_timer.h"
#include "freertos/FreeRTOS.h"
#include "freertos/task.h"

// IRAM-safe GPIO read (gpio_get_level lives in flash)
static inline uint32_t IRAM_ATTR gpio_read_iram(gpio_num_t pin)
{
	return gpio_ll_get_level(&GPIO, pin);
}

// Quadrature state table: [prev_AB][curr_AB] -> delta
// PEC09 with 15 detents gives 2 edges per detent per channel.
// We accumulate raw edges and convert to detents.
static volatile int32_t raw_count = 0;
static volatile uint8_t prev_ab = 0;

// Edge timestamps for velocity measurement
static volatile int64_t edge_time_prev = 0;
static volatile int64_t edge_time_last = 0;

// Speed tier thresholds (detents/sec)
#define SPEED_THRESH_MED   80   // not ~1 rev/s on 15-detent PEC09
#define SPEED_THRESH_FAST  300  // not ~2 rev/s
#define SPEED_HYST          5   // hysteresis band
#define STALENESS_US   150000   // 150ms: assume stopped

// Direction invert
static bool inverted = false;

// Button state
static volatile bool btn_raw = false;
static volatile bool btn_state = false;
static volatile bool btn_changed = false;
static volatile int64_t btn_last_change = 0;

#define BTN_DEBOUNCE_US 20000  // 20ms debounce

// Quadrature lookup: +1 = CW, -1 = CCW, 0 = invalid/no move
// DRAM_ATTR: must be in RAM, not flash, because ISR reads it while cache may be off
static const DRAM_ATTR int8_t quad_table[4][4] = {
	// to: 00  01  10  11
	{  0, -1, +1,  0 },  // from 00
	{ +1,  0,  0, -1 },  // from 01
	{ -1,  0,  0, +1 },  // from 10
	{  0, +1, -1,  0 },  // from 11
};

static void IRAM_ATTR encoder_isr(void *arg)
{
	uint8_t a = gpio_read_iram(ENC_PIN_A);
	uint8_t b = gpio_read_iram(ENC_PIN_B);
	uint8_t curr_ab = (a << 1) | b;

	int8_t delta = quad_table[prev_ab][curr_ab];
	prev_ab = curr_ab;

	if (delta != 0) {
		raw_count += delta;

		int64_t now = esp_timer_get_time();
		edge_time_prev = edge_time_last;
		edge_time_last = now;
	}
}

static void IRAM_ATTR button_isr(void *arg)
{
	int64_t now = esp_timer_get_time();
	if ((now - btn_last_change) < BTN_DEBOUNCE_US) {
		return;
	}

	bool level = !gpio_read_iram(ENC_PIN_SW);  // active LOW -> invert
	if (level != btn_raw) {
		btn_raw = level;
		btn_state = level;
		btn_changed = true;
		btn_last_change = now;
	}
}

void encoder_init(void)
{
	// Configure encoder pins as inputs (external pull-ups on board)
	gpio_config_t enc_cfg = {
		.pin_bit_mask = (1ULL << ENC_PIN_A) | (1ULL << ENC_PIN_B),
		.mode = GPIO_MODE_INPUT,
		.pull_up_en = GPIO_PULLUP_DISABLE,
		.pull_down_en = GPIO_PULLDOWN_DISABLE,
		.intr_type = GPIO_INTR_ANYEDGE,
	};
	gpio_config(&enc_cfg);

	// Configure button pin
	gpio_config_t btn_cfg = {
		.pin_bit_mask = (1ULL << ENC_PIN_SW),
		.mode = GPIO_MODE_INPUT,
		.pull_up_en = GPIO_PULLUP_DISABLE,
		.pull_down_en = GPIO_PULLDOWN_DISABLE,
		.intr_type = GPIO_INTR_ANYEDGE,
	};
	gpio_config(&btn_cfg);

	// Read initial state
	prev_ab = (gpio_get_level(ENC_PIN_A) << 1) | gpio_get_level(ENC_PIN_B);
	btn_state = !gpio_get_level(ENC_PIN_SW);
	btn_raw = btn_state;

	// Install ISR service and attach handlers
	gpio_install_isr_service(ESP_INTR_FLAG_IRAM);
	gpio_isr_handler_add(ENC_PIN_A, encoder_isr, NULL);
	gpio_isr_handler_add(ENC_PIN_B, encoder_isr, NULL);
	gpio_isr_handler_add(ENC_PIN_SW, button_isr, NULL);
}

void encoder_set_invert(bool invert)
{
	inverted = invert;
}

static portMUX_TYPE enc_mux = portMUX_INITIALIZER_UNLOCKED;

// EMA + hysteresis state (only accessed from encoder_read, not ISR)
static int32_t ema_speed = 0;      // fixed-point x256
static uint8_t last_tier = 0;

encoder_state_t encoder_read(void)
{
	// Snapshot volatile state
	portENTER_CRITICAL(&enc_mux);
	int32_t raw = raw_count;
	int64_t t_prev = edge_time_prev;
	int64_t t_last = edge_time_last;
	bool pressed = btn_state;
	bool changed = btn_changed;
	btn_changed = false;
	portEXIT_CRITICAL(&enc_mux);

	int32_t position = inverted ? -(raw / 2) : (raw / 2);

	// Compute instantaneous speed from last two edges
	int64_t now = esp_timer_get_time();
	int64_t age = t_last > 0 ? now - t_last : STALENESS_US;
	int32_t inst_speed = 0;

	if (t_prev > 0 && t_last > t_prev && age < STALENESS_US) {
		int64_t interval = t_last - t_prev;
		// 2 edges per detent: detents/sec = 500000 / interval_us
		inst_speed = (int32_t)(500000 / interval);
	}

	// EMA smoothing (fixed-point x256, alpha ~= 0.25)
	if (age >= STALENESS_US) {
		// Stopped: reset immediately
		ema_speed = 0;
	} else {
		ema_speed = (ema_speed * 3 + inst_speed * 256) / 4;
	}
	int32_t smooth = ema_speed / 256;

	// Classify speed tier with hysteresis
	uint8_t tier = last_tier;
	if (tier == 0) {
		if (smooth >= SPEED_THRESH_MED + SPEED_HYST)
			tier = 1;
	} else if (tier == 1) {
		if (smooth < SPEED_THRESH_MED - SPEED_HYST)
			tier = 0;
		else if (smooth >= SPEED_THRESH_FAST + SPEED_HYST)
			tier = 2;
	} else {
		if (smooth < SPEED_THRESH_FAST - SPEED_HYST)
			tier = 1;
	}
	last_tier = tier;

	(void)tier;  // multispeed disabled — always slow

	return (encoder_state_t){
		.position = position,
		.speed = 0,
		.fast = false,
		.button = pressed,
		.button_changed = changed,
	};
}

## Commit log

2026-03-29 encoder speed
2026-04-17 one partiition, no speed on encoder, wifi stability, menu order
    [partitions.csv]
